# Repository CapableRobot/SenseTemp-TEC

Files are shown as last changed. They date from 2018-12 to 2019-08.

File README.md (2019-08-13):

# SenseTemp TEC

Designed by [Capable Robot Components](http://capablerobot.com).  
Follow us on [Twitter](http://twitter.com/capablerobot) for product announcements and updates.

---

**SenseTemp TEC is available for purchase at [CrowdSupply](https://www.crowdsupply.com/capable-robot-components/sensetemp) & [Mouser](https://www.mouser.com/ProductDetail/Crowd-Supply/cs-sensetemp-03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).**  

## SenseTemp TEC Features 

## Specifications

## Feather Hosts

SenseTemp TEC is designed to mate with Adafruit Feather-compatible host modules, like:

* [Adafruit Feather M4 Express](https://www.adafruit.com/product/3857)
* [Adafruit Feather M0 Express](https://www.adafruit.com/product/3403)
* [Adafruit ESP32 Feather Host](https://www.adafruit.com/product/3405)

Note that the ES8266 Feather is **NOT** supported due to the limited IO on the ESP8266.  It does not have enough pins to support the four SPI devices of the SenseTemp.

## Software

## Hardware Revisions

* [CR2ERP](revisions/CR2ERP) : Released 2018-12-18.
	* Added high-side switch for fan control
	* Removed `!EN` pin as this product will not run off of battery power and there is no need to disable RTD converter chips.
	* Added 12v to 3v regulator (and disabled 5v to 3v regulator on host board).
	* Minor footprint changes.
	* Changed `PWM` pin for TEC control.
* [CRHVEF](revisions/CRHVEF) : Initial version released 2018-12-04.

## License Information

| **Type** | **License** |
| --- | --- |
| Hardware | Copyright Capable Robot Components 2018 <br><br>This documentation describes Open Hardware and is licensed under the [CERN OHL v1.2 or later](https://www.ohwr.org/licenses/cern-ohl/license_versions/v1.2). <br/><br/> You may redistribute and modify this documentation under the terms of the CERN OHL v.1.2.  This documentation is distributed WITHOUT ANY EXPRESS OR IMPLIED WARRANTY, INCLUDING OF MERCHANTABILITY, SATISFACTORY QUALITY AND FITNESS FOR A PARTICULAR PURPOSE. Please see the CERN OHL v.1.2 for applicable conditions |
| Software | [MIT License](tree/master/LICENSE.txt) |
| Documentation | [Creative Commons Attribution-ShareAlike](https://creativecommons.org/licenses/by-sa/4.0/) License |

More detailed information about the CERN License is available in the [license](license) folder and on the [CERN website](https://www.ohwr.org/projects/cernohl/wiki).

| **OSHW Certification** |

Coming Soon

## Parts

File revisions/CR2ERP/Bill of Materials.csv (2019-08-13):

Name | Mpn | Count | Device | Value | Package | Mfg | Cost | Description
C1,C22,C23,C24,C25 | CL31X226KOHN3NE | 5 | CAP-1206 | 22u 16v | 1206 | Samsung | 0.9049
C15,C16,C19,C26 | CL21A106KPFNNNE | 4 | CAP-0805 | 10u | 0805 | Samsung | 0.19060000000000002
C21 | CKG57NX7S1C107M500JH | 1 | CAP-2220 | 100u 16v | 2220 | TDK | 3.2068
C3,C4,C6,C7,C9,C10,C12,C13,C20 | MF-CAP-0603-0.1uF | 9 | CAP-0603 | 100n | 0603 | Generic
C5,C8,C11,C14 | MF-CAP-0603-0.01uF | 4 | CAP-0603 | 10n | 0603 | Generic
D1 | MBR120VLSFT3G | 1 | DIODE-SCHOTTKY-SOD-123 | MBR120 | SOD-123 | ON Semiconductor | 0.16
D3,D4 | SMAJ12A-13-F | 2 | DIODE-DO214AA | SMAJ12A | DO214AA | Diodes Inc. | 0.236
FB1,FB2,FB3,FB4 | BK1608HW601-T | 4 | FER-0603 | 600R | 0603 | Taiyo Yuden | 0.11350000000000002
L3,L4 | HCF1007-100-R | 2 | IND-HCF1007 | 10uH | IND-HCF1007 | Eaton | 4.3222
PWR | 43045-0200 | 1 | CONN-2-MFJR-RA |  | CONN-MFJR-RA-2X1 | Molex | 0.7328
Q3 | FDS6630A | 1 | MOSFET-NCH-SOIC8 | 6.5A/30V/38mΩ | SOIC127P600X175-8 | ON Semiconductor | 0.316
R2,R3,R18 | MF-RES-0603-1K | 3 | RES-0603 | 1k | 0603 | Generic
R20,R21 | MF-RES-0603-4.7K | 2 | RES-0603 | 4K7 | 0603 | Generic
R4,R6,R8,R10,R16,R17,R19,R23 | MF-RES-0603-10K | 8 | RES-0603 | 10k | 0603 | Generic
R5,R7,R9,R11 | ERA3ARW432V | 4 | RES-0603 | 4k3 0.05% | 0603 | Panasonic | 1.7916
RTD1 | 3221-16-0300-00 | 1 | CONN-16-ZT |  | CONN-2X8-050-SMT-ZT | CNC Tech | 0.946
TEC/FAN | 43045-0400 | 1 | CONN-4-MFJR-RA |  | CONN-MFJR-RA-2X2 | Molex | 1.1052
U1 | NCP1117ST50T3G | 1 | VREG-LDO | NCP1117 3v3 | SOT230P700X180-4 | ON Semiconductor | 0.238
U10 | NCV8461DR2G | 1 | NCV8461 |  | SOIC127P600X175-8 | ON Semiconductor | 0.753
U2 | AT21CS01-STUM10-T | 1 | AT21CS01 |  | SOT23 | Microchip | 0.1836
U3,U4,U5,U6 | MAX31865ATP+ | 4 | MAX31865 |  | QFN65P500X500X100-21T325 | Maxim Integrated | 12.336
U7 | AP2112K-3.3TRG1 | 1 | MIC5225 | 3v3 | SOT25 | Diodes Inc. | 0.15
U8 | VNH5019ATR-E | 1 | VNH5019 |  | SOP100P1900X235-30-EP | STMicroelectronics | 5.75

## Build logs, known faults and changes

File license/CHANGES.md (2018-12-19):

Here we are compiling a community changelog.

If you come up with a modification of our designs, please share it
with the community, log your changes below, and upload the files to
our GitHub repository.

# Change Format

**NAME** on DATE by *Your name*.
Description of modification

# Change Log

* **[CR2ERP](https://github.com/CapableRobot/SenseTemp/tree/master/revisions/CR2ERP)** on 2018-12-18 by *Chris Osterwood*
	* Added high-side switch for fan control
	* Removed `!EN` pin as this product will not run off of battery power and there is no need to disable RTD converter chips.
	* Added 12v to 3v regulator (and disable 5v to 3v regulator on host board).
	* Minor footprint changes.
	* Changed `PWM` pin for TEC control.
	* Add user LED near RTD connector.
* **[CRHVEF](https://github.com/CapableRobot/SenseTemp/tree/master/revisions/CRHVEF)** 2018-12-04 by *Chris Osterwood*

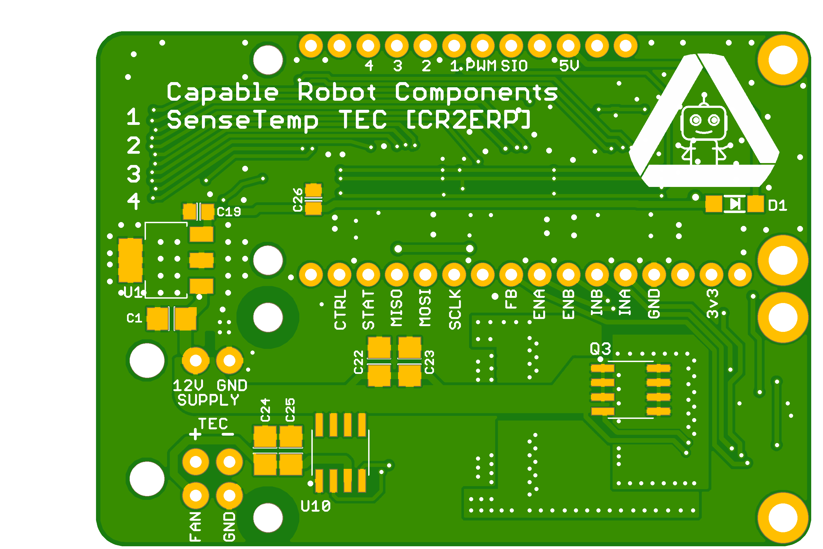
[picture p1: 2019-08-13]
revisions/CR2ERP/SenseThermo TEC - CR2ERP - Bottom.png

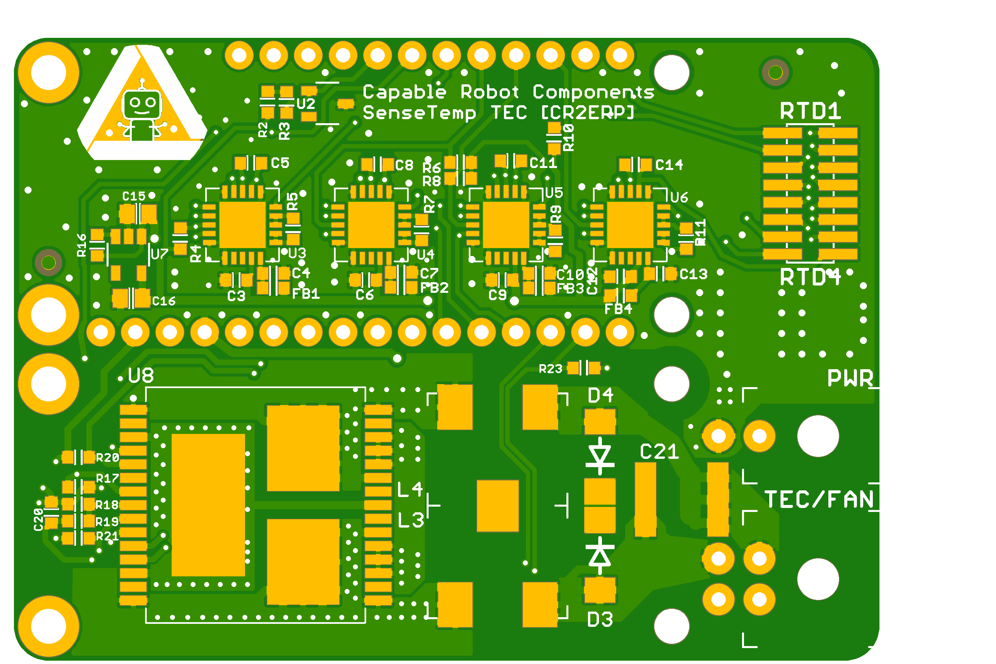
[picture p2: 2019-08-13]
revisions/CR2ERP/SenseThermo TEC - CR2ERP - Top.png

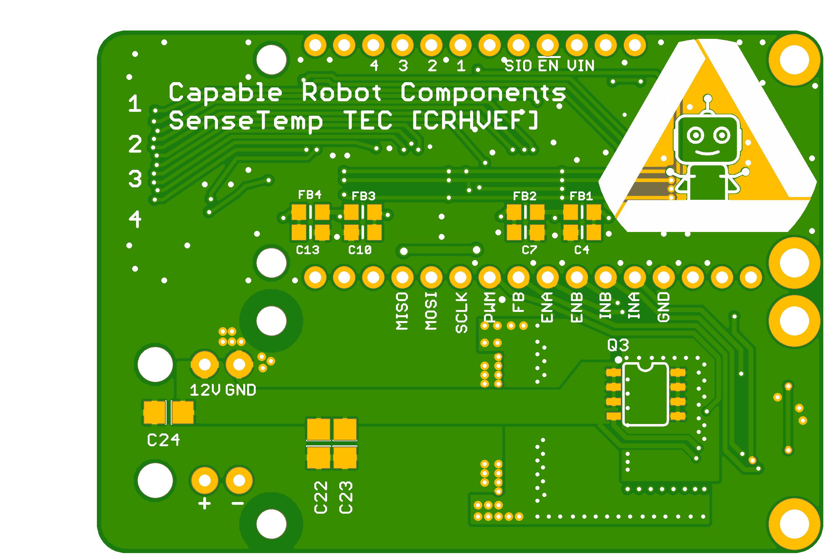
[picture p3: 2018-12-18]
revisions/CRHVEF/SenseThermo TEC - CRHVEF - bottom.png

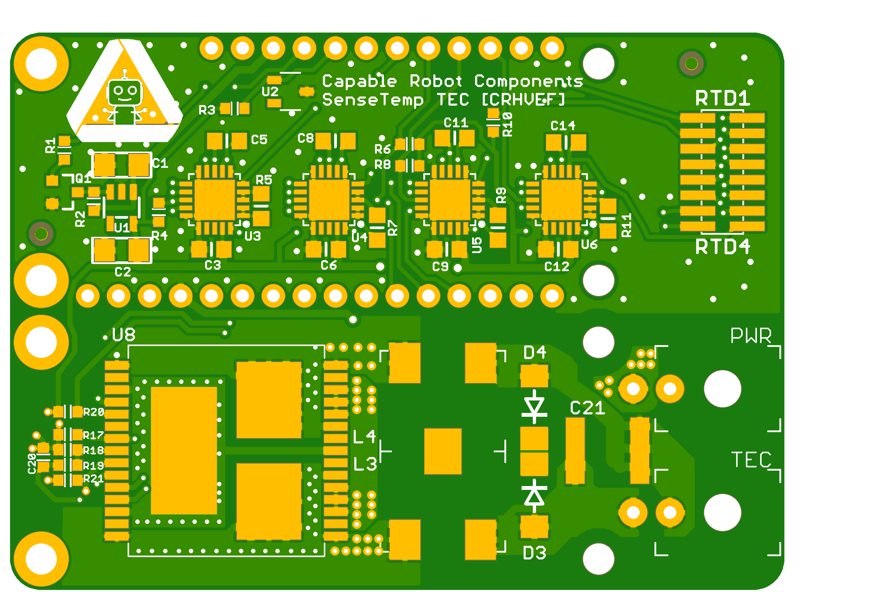
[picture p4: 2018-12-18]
revisions/CRHVEF/SenseThermo TEC - CRHVEF - top.png

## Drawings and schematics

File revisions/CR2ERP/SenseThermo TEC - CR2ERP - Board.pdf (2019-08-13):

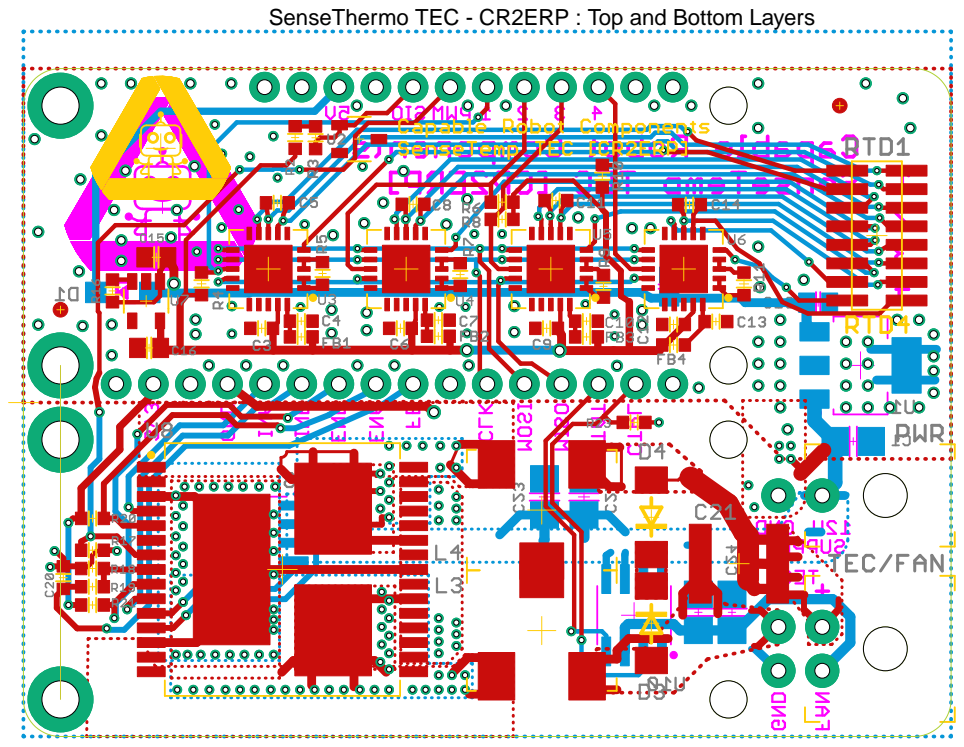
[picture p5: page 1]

SenseThermo TEC - CR2ERP : Top and Bottom Layers

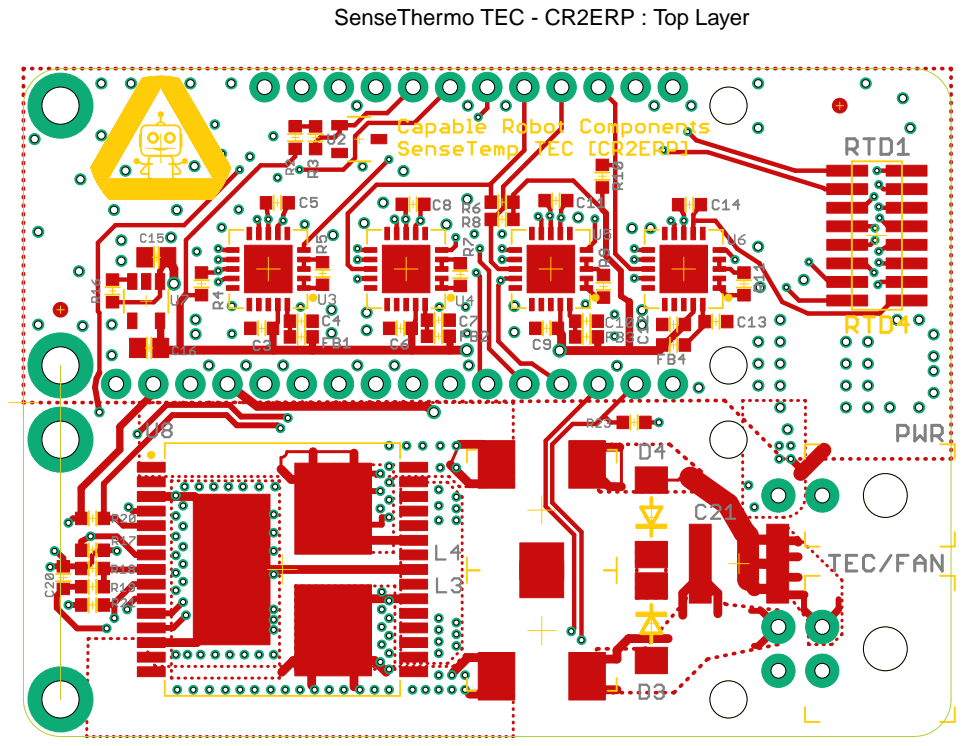
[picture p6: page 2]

SenseThermo TEC - CR2ERP : Top Layer

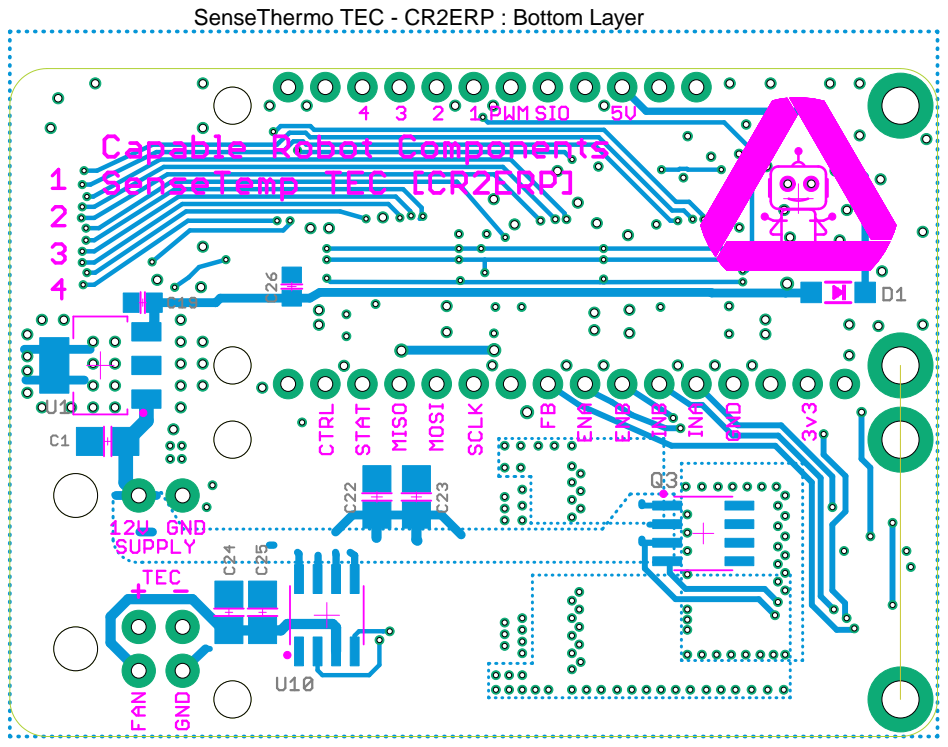
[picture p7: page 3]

SenseThermo TEC - CR2ERP : Bottom Layer

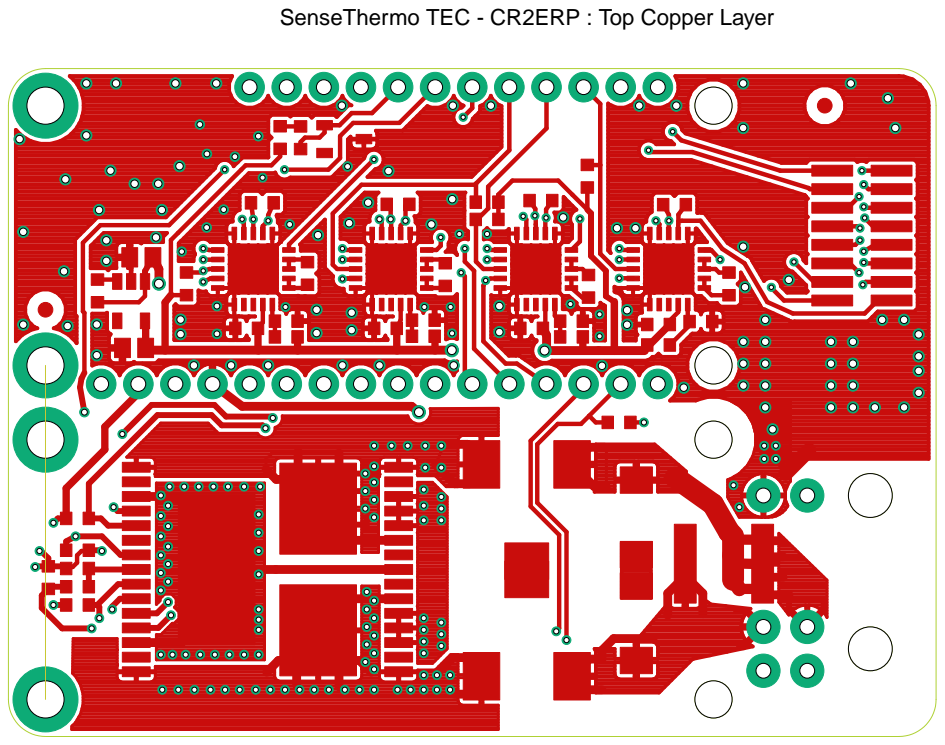
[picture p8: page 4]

SenseThermo TEC - CR2ERP : Top Copper Layer

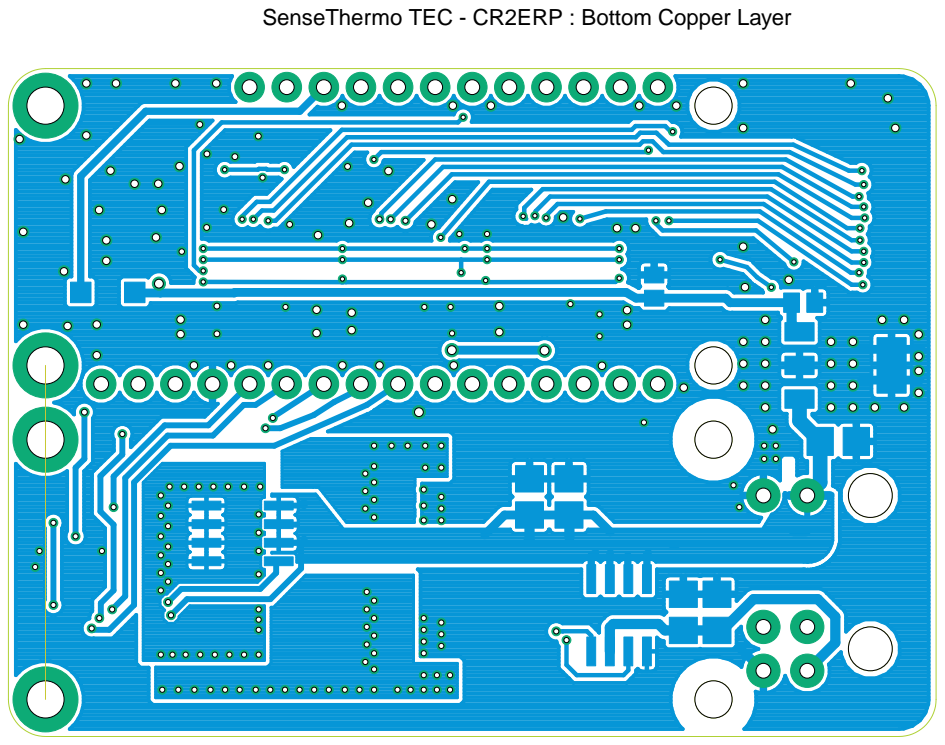
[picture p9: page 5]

SenseThermo TEC - CR2ERP : Bottom Copper Layer

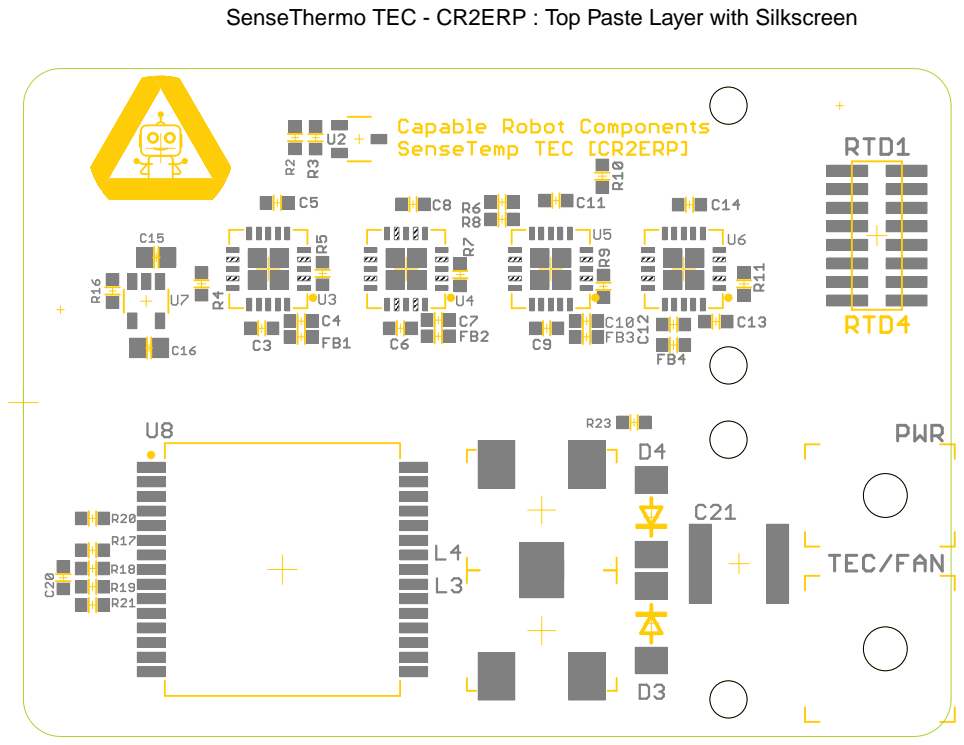
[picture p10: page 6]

SenseThermo TEC - CR2ERP : Top Paste Layer with Silkscreen

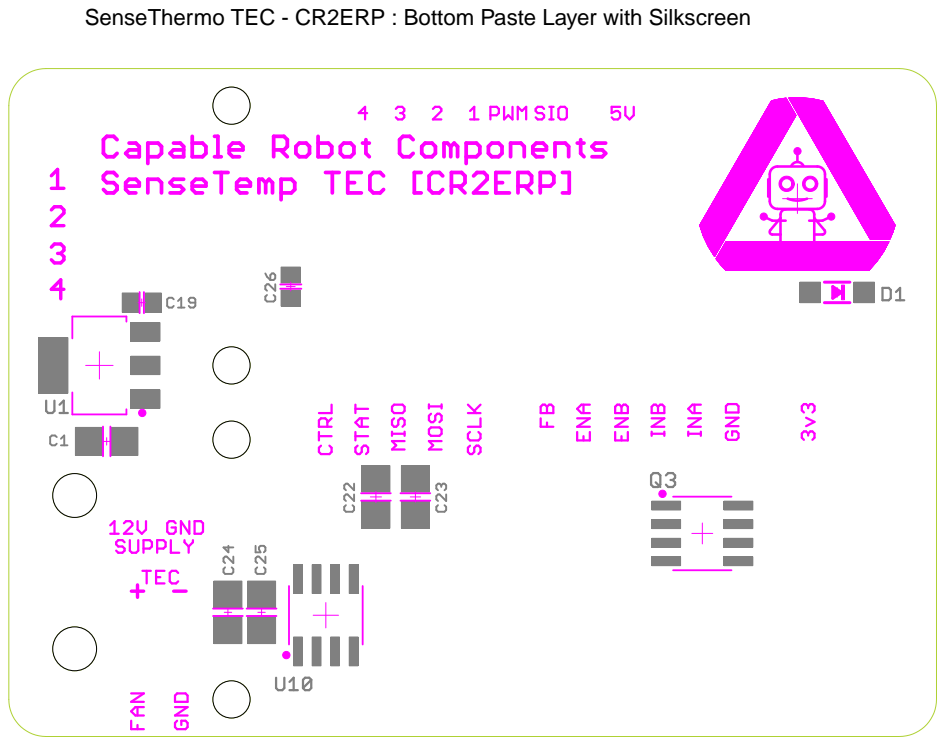
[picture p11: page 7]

SenseThermo TEC - CR2ERP : Bottom Paste Layer with Silkscreen

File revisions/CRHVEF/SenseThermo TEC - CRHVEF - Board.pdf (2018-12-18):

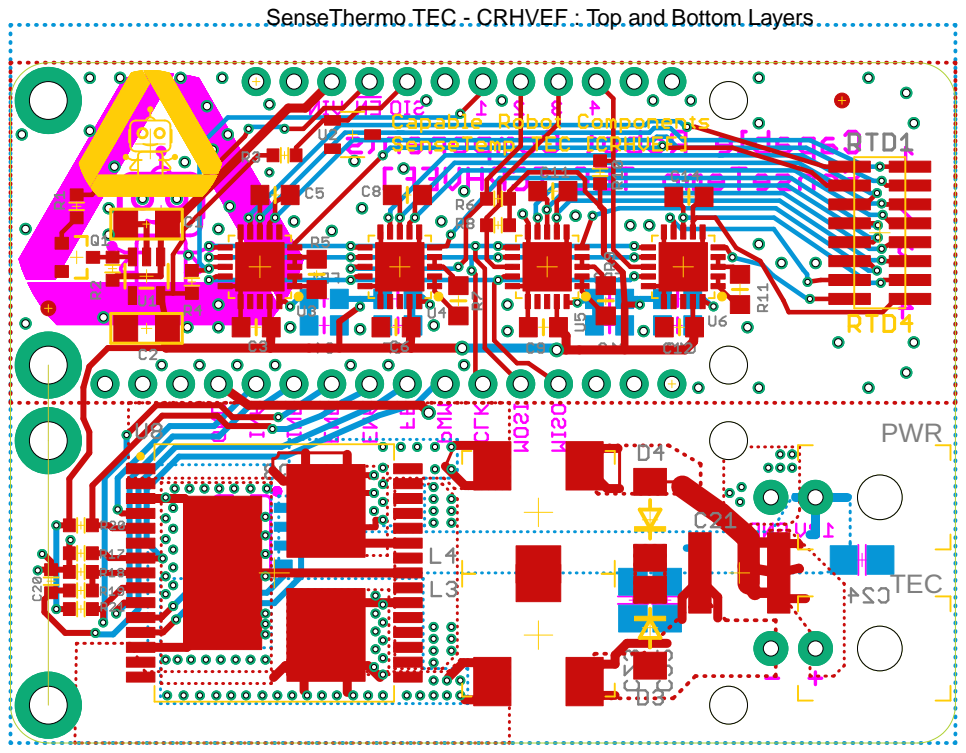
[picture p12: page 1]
TEC; PWR

SenseThermo TEC - CRHVEF : Top and Bottom Layers

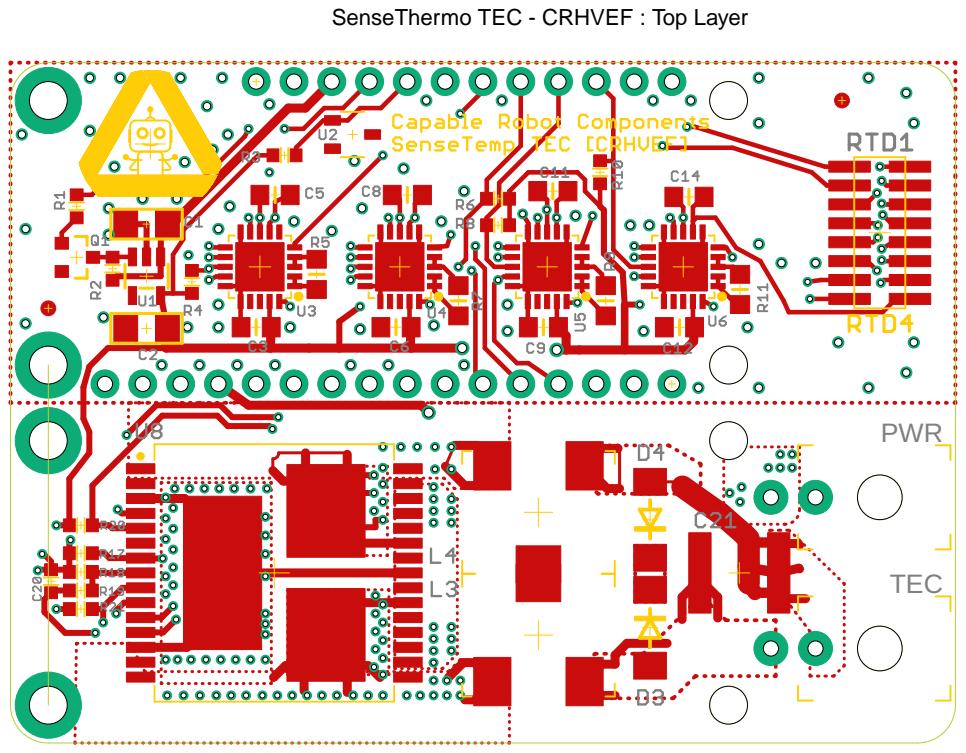
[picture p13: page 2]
TEC; PWR

SenseThermo TEC - CRHVEF : Top Layer

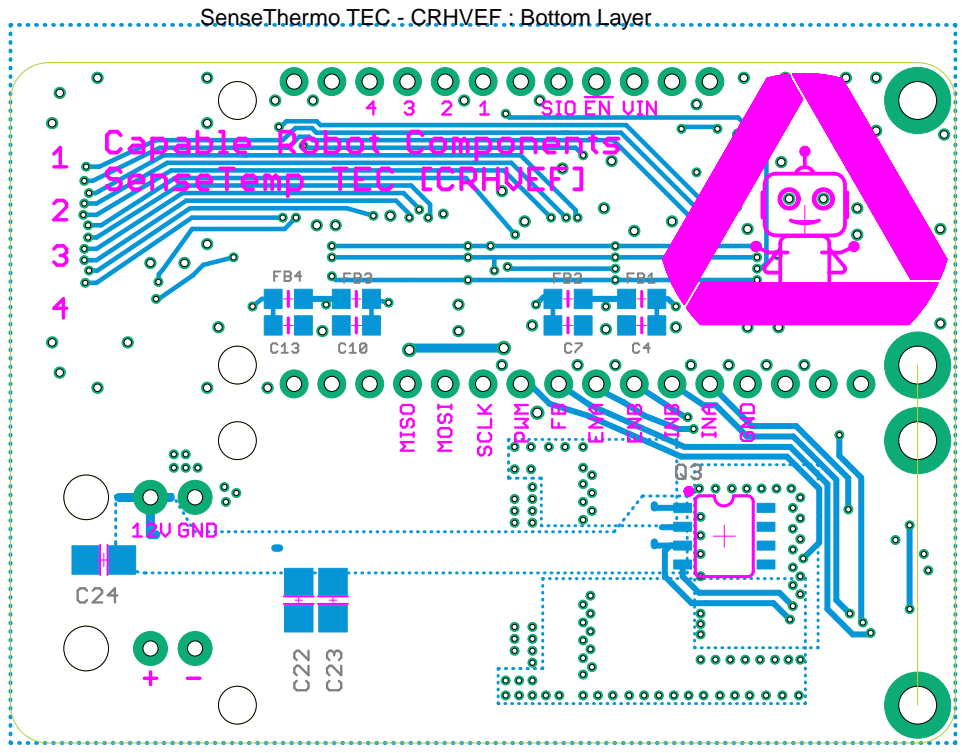
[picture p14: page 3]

SenseThermo TEC - CRHVEF : Bottom Layer

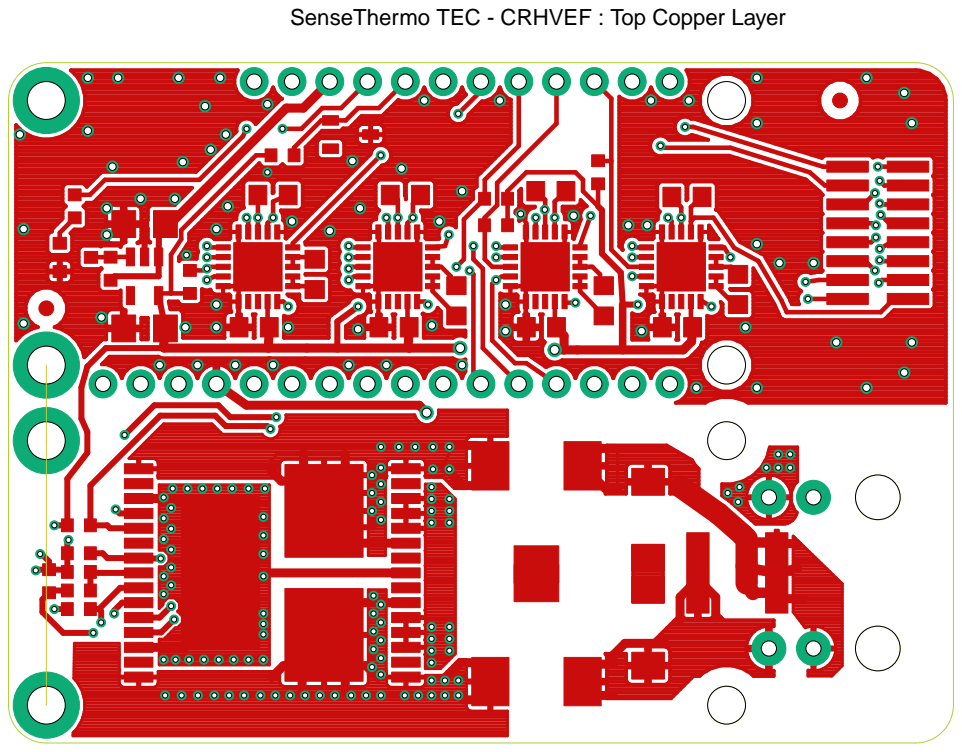
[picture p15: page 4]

SenseThermo TEC - CRHVEF : Top Copper Layer

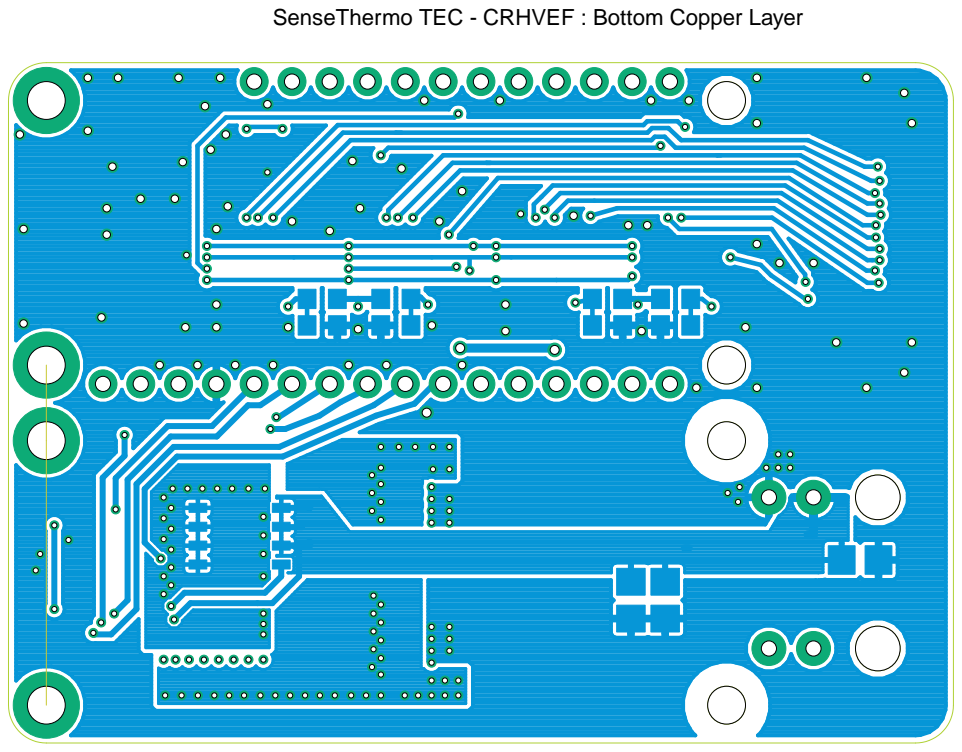
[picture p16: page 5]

SenseThermo TEC - CRHVEF : Bottom Copper Layer

TEC; PWR

SenseThermo TEC - CRHVEF : Top Paste Layer with Silkscreen


SenseThermo TEC - CRHVEF : Bottom Paste Layer with Silkscreen

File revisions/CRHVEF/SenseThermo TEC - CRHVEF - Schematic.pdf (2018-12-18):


Name | Revision Capable Robot Components
SenseTemp TEC | CRHVEF | License 12/18/18 4:24 PM 1/4 CERN OHL v1.2

URL
https://github.com/CapableRobot/SenseTemp-TEC


4x RTD resistance at 0°C
Use high quality 1% or better resistors

Name | Revision Capable Robot Components
SenseTemp TEC | CRHVEF | License 12/18/18 4:24 PM 2/4 CERN OHL v1.2

URL
https://github.com/CapableRobot/SenseTemp-TEC


Name | Revision Capable Robot Components
SenseTemp TEC | CRHVEF | License 12/18/18 4:24 PM 3/4 CERN OHL v1.2

URL
https://github.com/CapableRobot/SenseTemp-TEC


Name | Revision Capable Robot Components
SenseTemp TEC | CRHVEF | License 12/18/18 4:24 PM 4/4 CERN OHL v1.2

URL
https://github.com/CapableRobot/SenseTemp-TEC





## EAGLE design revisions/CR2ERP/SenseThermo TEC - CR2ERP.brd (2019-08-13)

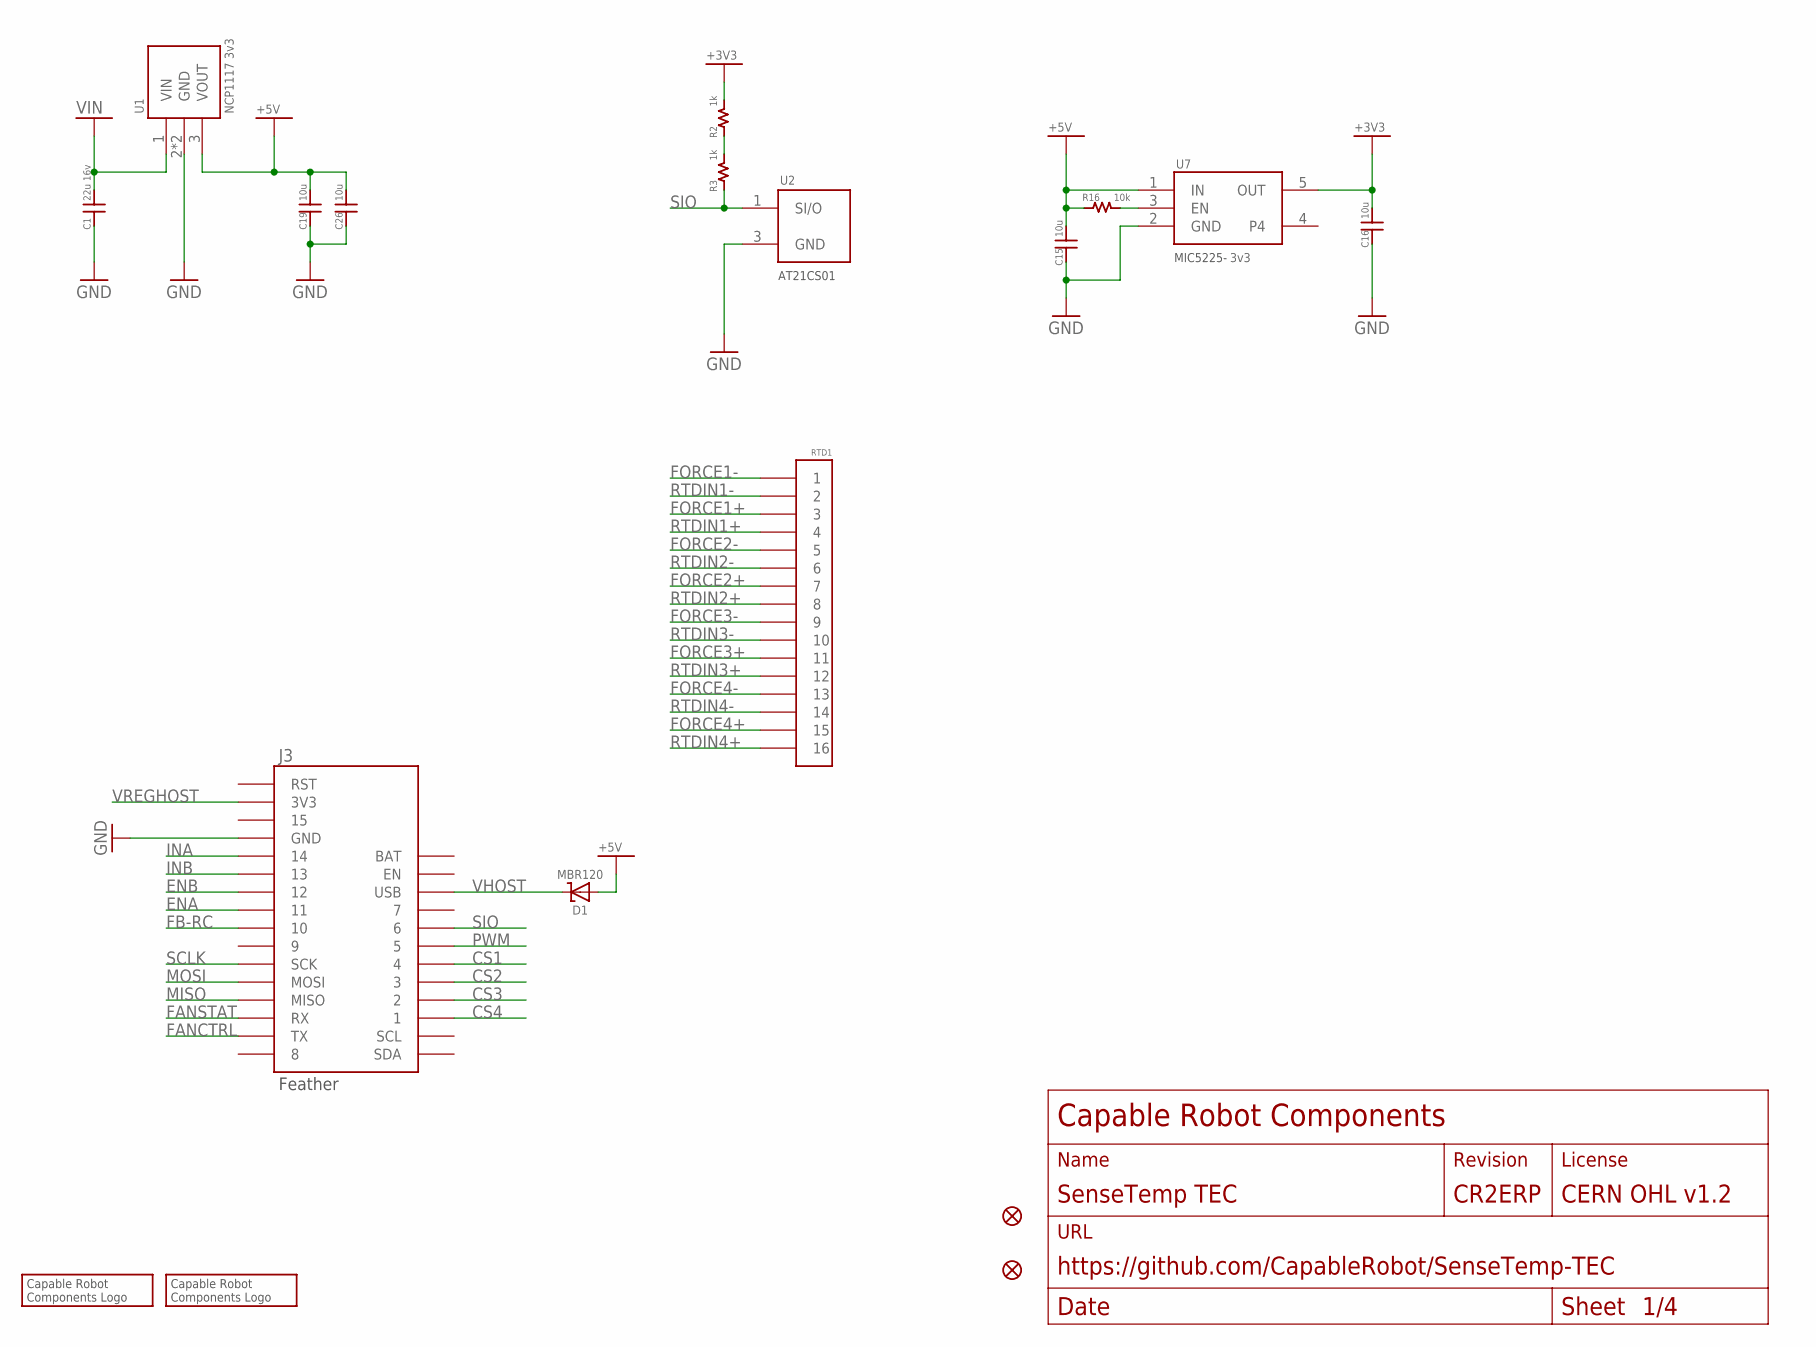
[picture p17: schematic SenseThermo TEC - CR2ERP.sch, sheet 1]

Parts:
C1: 22u 16v; 1206
C15, C16, C19, C26: 10u; 0805
D1: MBR120; SOD-123; MPN MBR120VLSFT3G
FID1, FID2: FIDUCIAL""; FIDUCIAL_1MM
J3: FEATHERPTH; FEATHER-PTH
LOGO1: CRC-LOGO7SILK; CRC-LOGO-7-SILK
LOGO2: CRC-LOGO5; CRC-LOGO-5
R2, R3: 1k; 0603
R16: 10k; 0603
RTD1: CONN-16ZT; CONN-2X8-050-SMT-ZT; MPN 3221-16-0300-00
U1: NCP1117 3v3; SOT230P700X180-4; MPN NCP1117ST50T3G
U2: AT21CS01; SOT23
U7: 3v3; SOT25

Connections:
+3V3: C16.P$2, R2.2, U7.5 (OUT); also elsewhere on the board
+5V: C15.P$2, C19.P$2, C26.P$2, D1.A, R16.1, U1.3 (VOUT), U7.1 (IN)
CS1: J3.4; also elsewhere on the board
CS2: J3.3; also elsewhere on the board
CS3: J3.2; also elsewhere on the board
CS4: J3.1; also elsewhere on the board
ENA: J3.11; also elsewhere on the board
ENB: J3.12; also elsewhere on the board
FANCTRL: J3.TX; also elsewhere on the board
FANSTAT: J3.RX; also elsewhere on the board
FB-RC: J3.10; also elsewhere on the board
FORCE1+: RTD1.3; also elsewhere on the board
FORCE1-: RTD1.1; also elsewhere on the board
FORCE2+: RTD1.7; also elsewhere on the board
FORCE2-: RTD1.5; also elsewhere on the board
FORCE3+: RTD1.11; also elsewhere on the board
FORCE3-: RTD1.9; also elsewhere on the board
FORCE4+: RTD1.15; also elsewhere on the board
FORCE4-: RTD1.13; also elsewhere on the board
GND: C1.P$1, C15.P$1, C16.P$1, C19.P$1, C26.P$1, J3.GND, U1.2 (GND), U1.4 (GND), U2.3 (GND), U7.2 (GND); also elsewhere on the board
INA: J3.14; also elsewhere on the board
INB: J3.13; also elsewhere on the board
MISO: J3.MISO; also elsewhere on the board
MOSI: J3.MOSI; also elsewhere on the board
unnamed: R2.1, R3.2
unnamed: R16.2, U7.3 (EN)
PWM: J3.5; also elsewhere on the board
RTDIN1+: RTD1.4; also elsewhere on the board
RTDIN1-: RTD1.2; also elsewhere on the board
RTDIN2+: RTD1.8; also elsewhere on the board
RTDIN2-: RTD1.6; also elsewhere on the board
RTDIN3+: RTD1.12; also elsewhere on the board
RTDIN3-: RTD1.10; also elsewhere on the board
RTDIN4+: RTD1.16; also elsewhere on the board
RTDIN4-: RTD1.14; also elsewhere on the board
SCLK: J3.SCK; also elsewhere on the board
SIO: J3.6, R3.1, U2.1 (SI/O)
VHOST: D1.C, J3.USB
VIN: C1.P$2, U1.1 (VIN); also elsewhere on the board
VREGHOST: J3.3V3; also elsewhere on the board

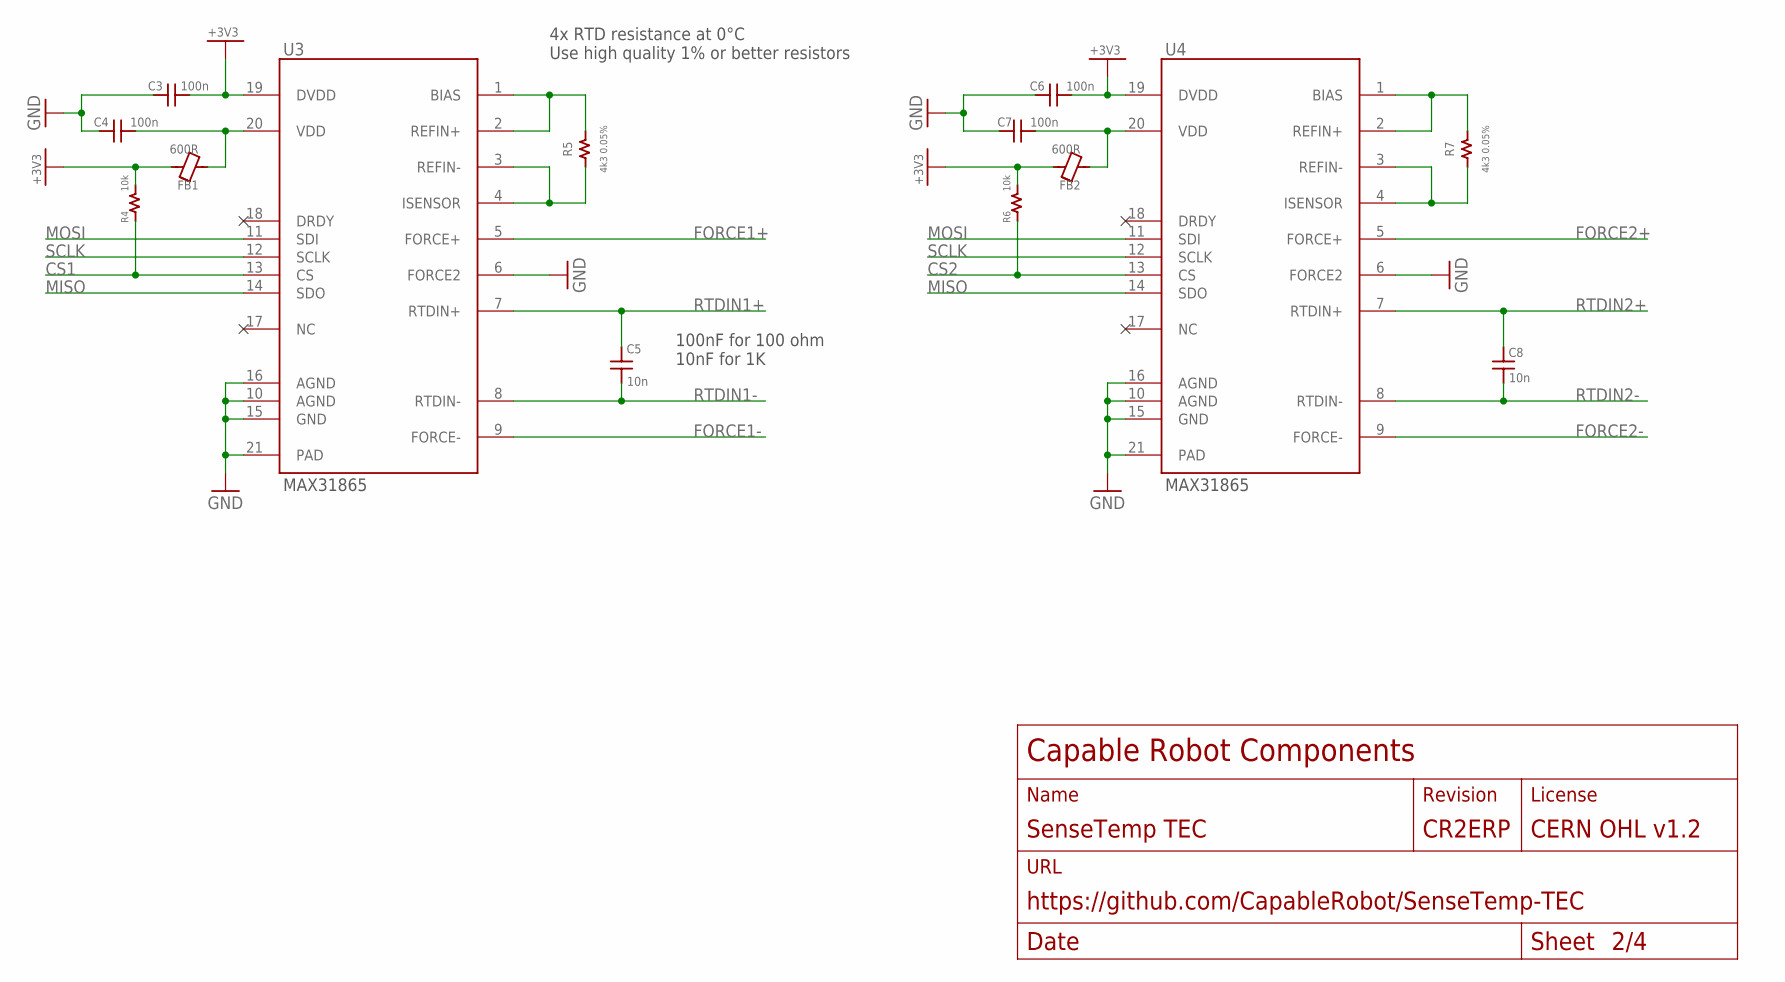
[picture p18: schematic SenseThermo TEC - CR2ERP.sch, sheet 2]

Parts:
C3, C4, C6, C7: 100n; 0603
C5, C8: 10n; 0603
FB1, FB2: 600R; 0603
R4, R6: 10k; 0603
R5, R7: 4k3 0.05%; 0603
U3, U4: MAX31865; QFN65P500X500X100-21T325

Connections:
+3V3: C3.1, C6.1, FB1.2, FB2.2, R4.2, R6.2, U3.19 (DVDD), U4.19 (DVDD); also elsewhere on the board
CS1: R4.1, U3.13 (CS); also elsewhere on the board
CS2: R6.1, U4.13 (CS); also elsewhere on the board
FORCE1+: U3.5 (FORCE+); also elsewhere on the board
FORCE1-: U3.9 (FORCE-); also elsewhere on the board
FORCE2+: U4.5 (FORCE+); also elsewhere on the board
FORCE2-: U4.9 (FORCE-); also elsewhere on the board
GND: C3.2, C4.2, C6.2, C7.2, U3.6 (FORCE2), U3.10 (AGND), U3.15 (GND), U3.16 (AGND), U3.21 (PAD), U4.6 (FORCE2), U4.10 (AGND), U4.15 (GND), U4.16 (AGND), U4.21 (PAD); also elsewhere on the board
MISO: U3.14 (SDO), U4.14 (SDO); also elsewhere on the board
MOSI: U3.11 (SDI), U4.11 (SDI); also elsewhere on the board
unnamed: R5.2, U3.1 (BIAS), U3.2 (REFIN+)
unnamed: R5.1, U3.3 (REFIN-), U3.4 (ISENSOR)
unnamed: C4.1, FB1.1, U3.20 (VDD)
unnamed: R7.2, U4.1 (BIAS), U4.2 (REFIN+)
unnamed: R7.1, U4.3 (REFIN-), U4.4 (ISENSOR)
unnamed: C7.1, FB2.1, U4.20 (VDD)
RTDIN1+: C5.1, U3.7 (RTDIN+); also elsewhere on the board
RTDIN1-: C5.2, U3.8 (RTDIN-); also elsewhere on the board
RTDIN2+: C8.1, U4.7 (RTDIN+); also elsewhere on the board
RTDIN2-: C8.2, U4.8 (RTDIN-); also elsewhere on the board
SCLK: U3.12 (SCLK), U4.12 (SCLK); also elsewhere on the board

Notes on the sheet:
4x RTD resistance at 0°C Use high quality 1% or better resistors
100nF for 100 ohm 10nF for 1K

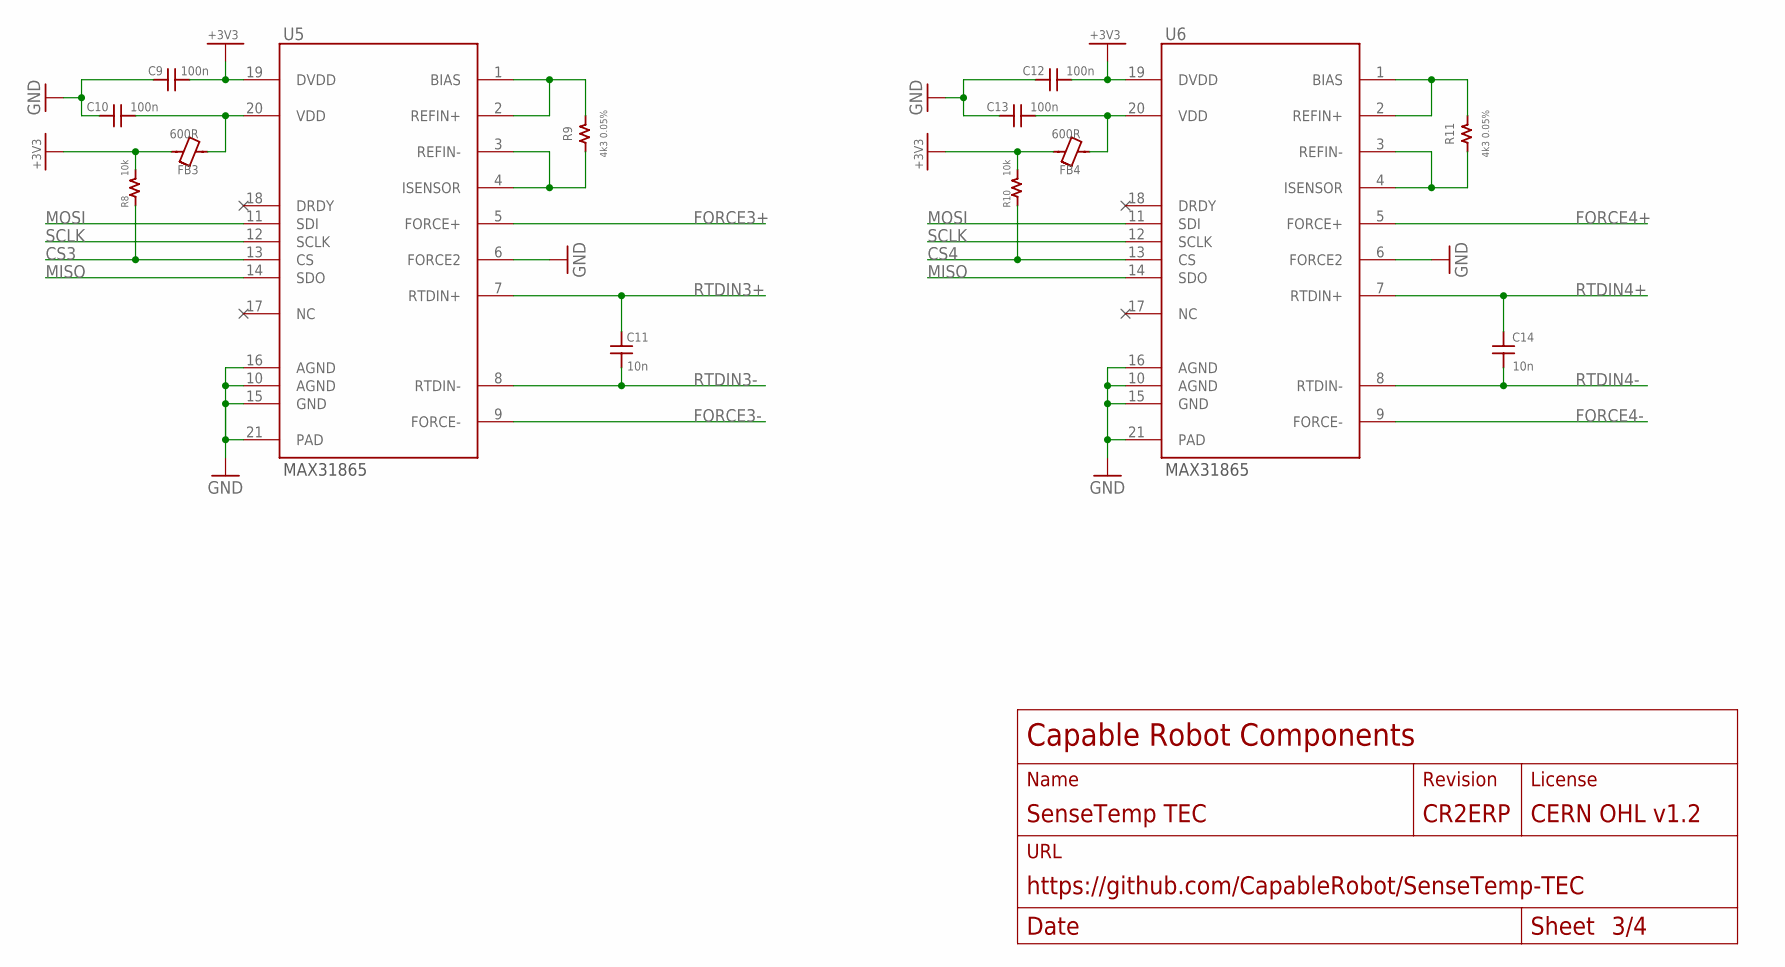
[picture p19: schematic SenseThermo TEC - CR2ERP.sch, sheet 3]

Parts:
C9, C10, C12, C13: 100n; 0603
C11, C14: 10n; 0603
FB3, FB4: 600R; 0603
R8, R10: 10k; 0603
R9, R11: 4k3 0.05%; 0603
U5, U6: MAX31865; QFN65P500X500X100-21T325

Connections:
+3V3: C9.1, C12.1, FB3.2, FB4.2, R8.2, R10.2, U5.19 (DVDD), U6.19 (DVDD); also elsewhere on the board
CS3: R8.1, U5.13 (CS); also elsewhere on the board
CS4: R10.1, U6.13 (CS); also elsewhere on the board
FORCE3+: U5.5 (FORCE+); also elsewhere on the board
FORCE3-: U5.9 (FORCE-); also elsewhere on the board
FORCE4+: U6.5 (FORCE+); also elsewhere on the board
FORCE4-: U6.9 (FORCE-); also elsewhere on the board
GND: C9.2, C10.2, C12.2, C13.2, U5.6 (FORCE2), U5.10 (AGND), U5.15 (GND), U5.16 (AGND), U5.21 (PAD), U6.6 (FORCE2), U6.10 (AGND), U6.15 (GND), U6.16 (AGND), U6.21 (PAD); also elsewhere on the board
MISO: U5.14 (SDO), U6.14 (SDO); also elsewhere on the board
MOSI: U5.11 (SDI), U6.11 (SDI); also elsewhere on the board
unnamed: R9.2, U5.1 (BIAS), U5.2 (REFIN+)
unnamed: R9.1, U5.3 (REFIN-), U5.4 (ISENSOR)
unnamed: C10.1, FB3.1, U5.20 (VDD)
unnamed: R11.2, U6.1 (BIAS), U6.2 (REFIN+)
unnamed: R11.1, U6.3 (REFIN-), U6.4 (ISENSOR)
unnamed: C13.1, FB4.1, U6.20 (VDD)
RTDIN3+: C11.1, U5.7 (RTDIN+); also elsewhere on the board
RTDIN3-: C11.2, U5.8 (RTDIN-); also elsewhere on the board
RTDIN4+: C14.1, U6.7 (RTDIN+); also elsewhere on the board
RTDIN4-: C14.2, U6.8 (RTDIN-); also elsewhere on the board
SCLK: U5.12 (SCLK), U6.12 (SCLK); also elsewhere on the board

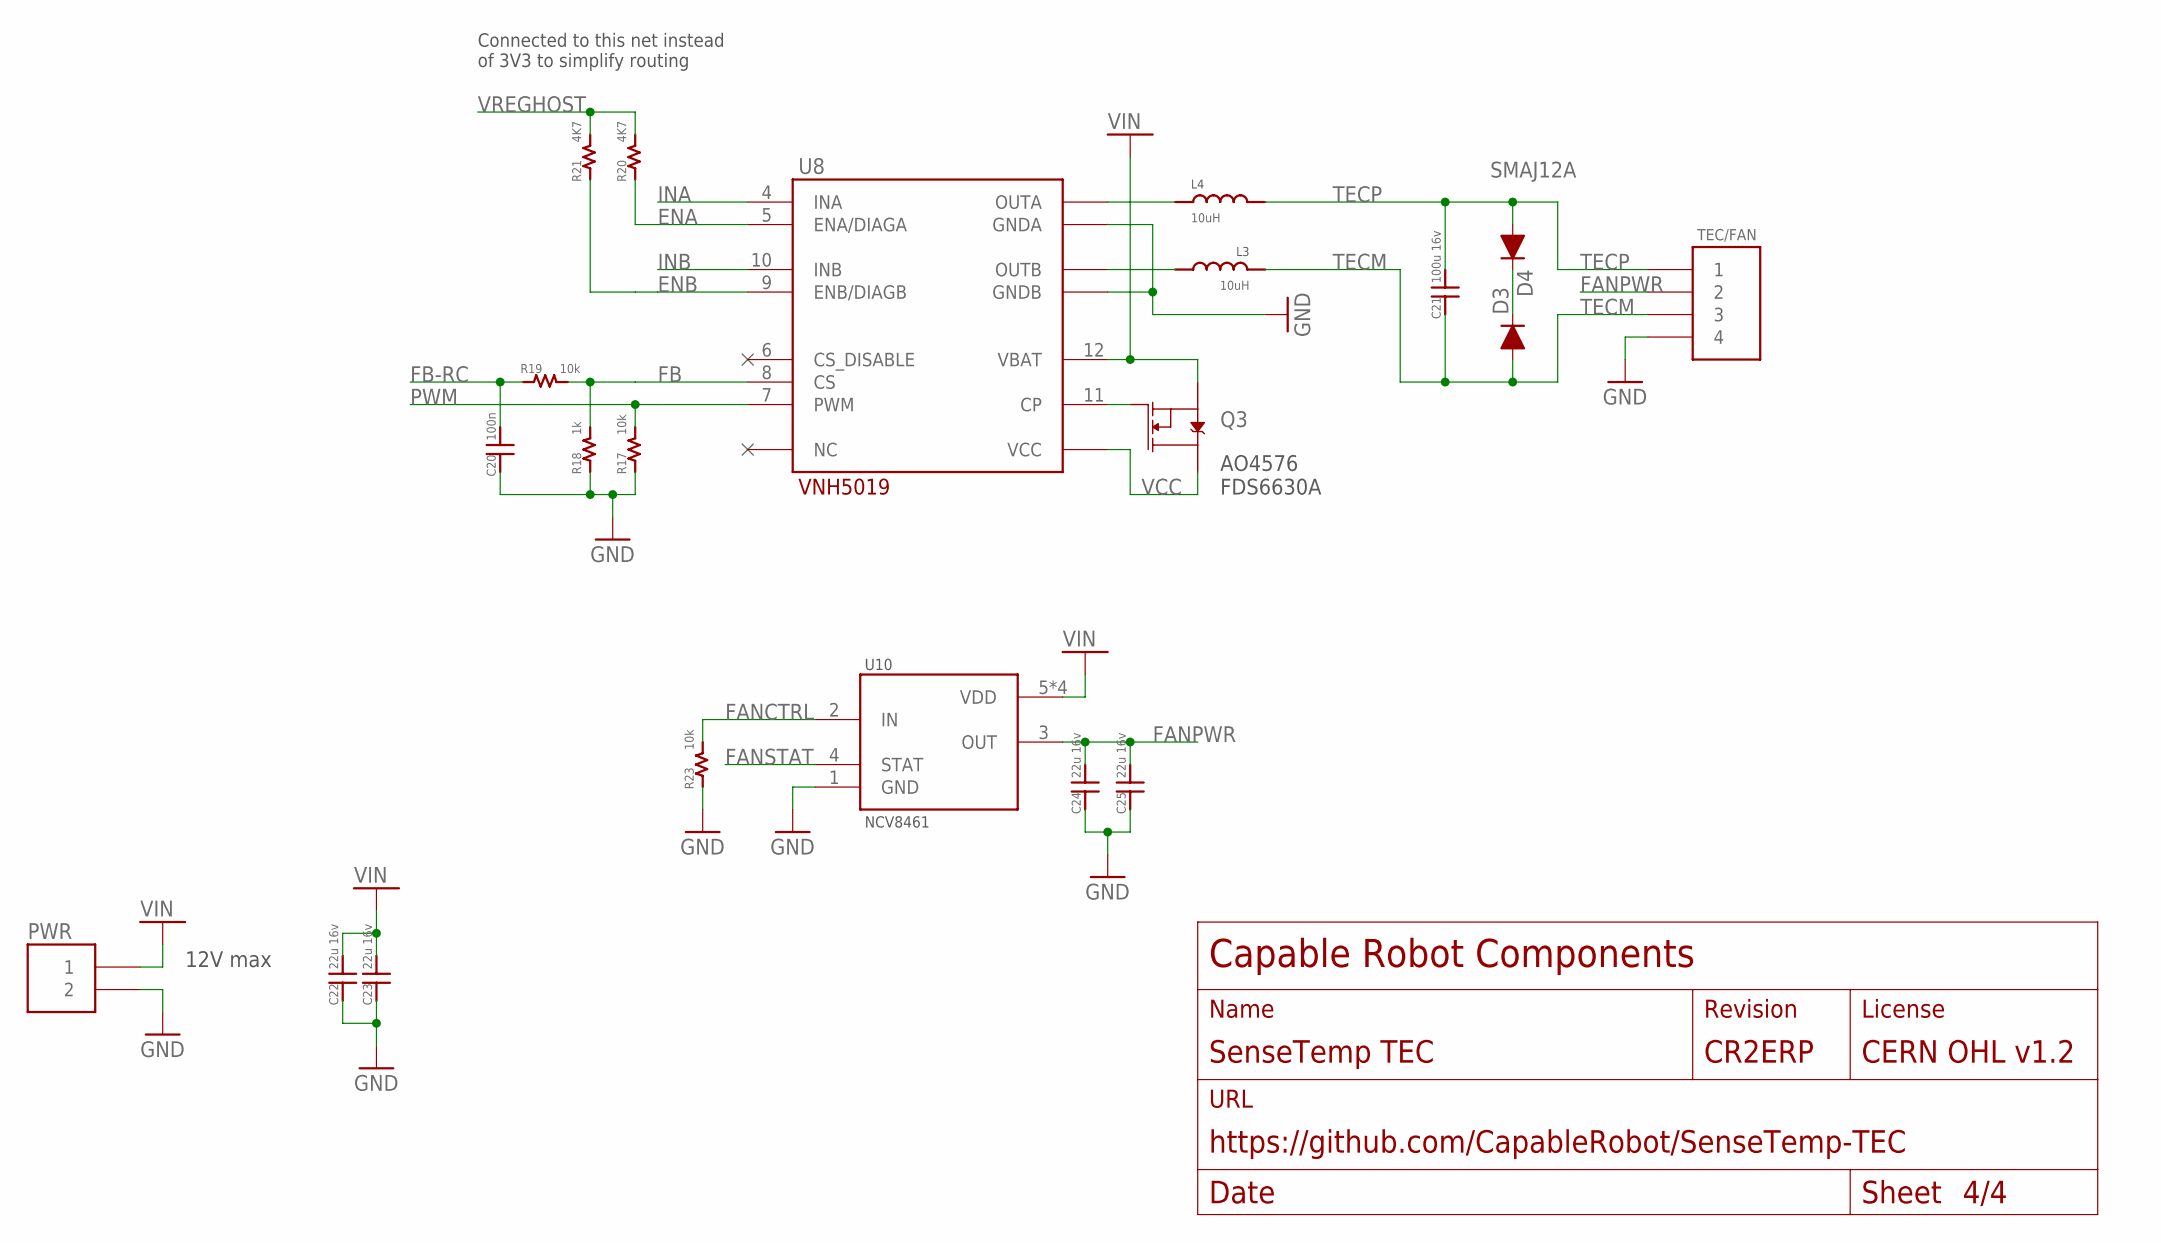
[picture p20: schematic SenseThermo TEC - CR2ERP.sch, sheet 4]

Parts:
C20: 100n; 0603
C21: 100u 16v; 2220
C22, C23, C24, C25: 22u 16v; 1206
D3, D4: SMAJ12A; DO214AA; MPN SMAJ12A-13-F
L3, L4: 10uH; IND-HCF1007
PWR: CONN-2-MFJR-RA; CONN-MFJR-RA-2X1
Q3: 6.5A/30V/38mΩ; SOIC127P600X175-8; MPN FDS6630A
R17, R19, R23: 10k; 0603
R18: 1k; 0603
R20, R21: 4K7; 0603
TEC/FAN: CONN-4-MFJR-RA; CONN-MFJR-RA-2X2
U8: VNH5019; SOP100P1900X235-30-EP
U10: NCV8461; SOIC127P600X175-8; MPN NCV8461DR2G

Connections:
CP1: Q3.4 (G), U8.11 (CP)
ENA: R20.1, U8.5 (ENA/DIAGA); also elsewhere on the board
ENB: R21.1, U8.9 (ENB/DIAGB); also elsewhere on the board
FANCTRL: R23.2, U10.2 (IN); also elsewhere on the board
FANPWR: C24.P$2, C25.P$2, TEC/FAN.2, U10.3 (OUT)
FANSTAT: U10.4 (STAT); also elsewhere on the board
FB: R18.2, R19.2, U8.8 (CS)
FB-RC: C20.2, R19.1; also elsewhere on the board
GND: C20.1, C22.P$1, C23.P$1, C24.P$1, C25.P$1, PWR.2, R17.1, R18.1, R23.1, TEC/FAN.4, U8.18 (GNDB), U8.19 (GNDB), U8.20 (GNDB), U8.26 (GNDA), U8.27 (GNDA), U8.28 (GNDA), U10.1 (GND); also elsewhere on the board
INA: U8.4 (INA); also elsewhere on the board
INB: U8.10 (INB); also elsewhere on the board
OUTA1: L4.1, U8.1 (OUTA), U8.25 (OUTA), U8.30 (OUTA), U8.OUTA
OUTB1: L3.2, U8.15 (OUTB), U8.16 (OUTB), U8.21 (OUTB), U8.OUTB
PWM: R17.2, U8.7 (PWM); also elsewhere on the board
SNUB1: D3.C, D4.C
TECM: C21.1, D3.A, L3.1, TEC/FAN.3
TECP: C21.2, D4.A, L4.2, TEC/FAN.1
VCC: Q3.5 (D), Q3.6 (D), Q3.7 (D), Q3.8 (D), U8.3 (VCC), U8.13 (VCC), U8.23 (VCC), U8.VCC
VIN: C22.P$2, C23.P$2, PWR.1, Q3.1 (S), Q3.2 (S), Q3.3 (S), U8.12 (VBAT), U10.5 (VDD), U10.6 (VDD), U10.7 (VDD), U10.8 (VDD); also elsewhere on the board
VREGHOST: R20.2, R21.2; also elsewhere on the board

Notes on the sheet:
12V max
AO4576 FDS6630A
Connected to this net instead of 3V3 to simplify routing

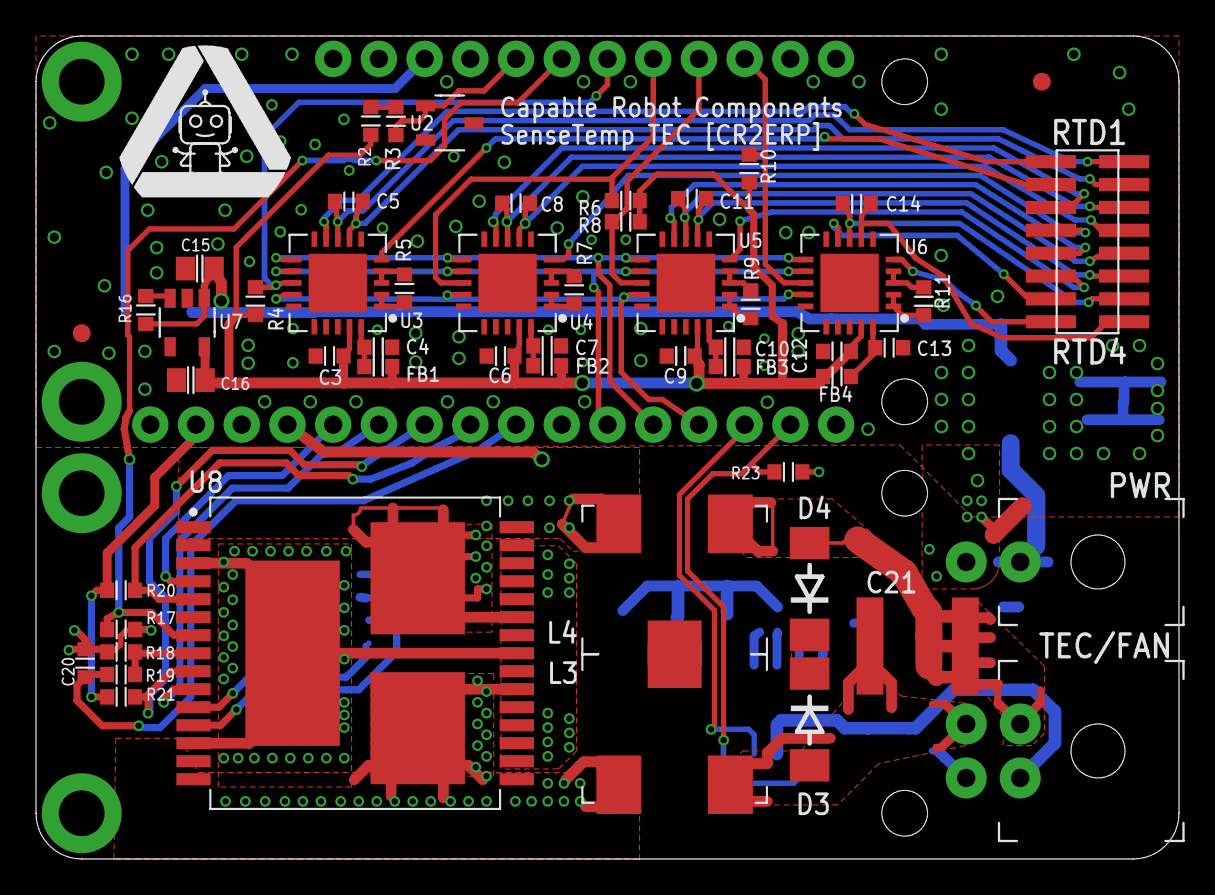
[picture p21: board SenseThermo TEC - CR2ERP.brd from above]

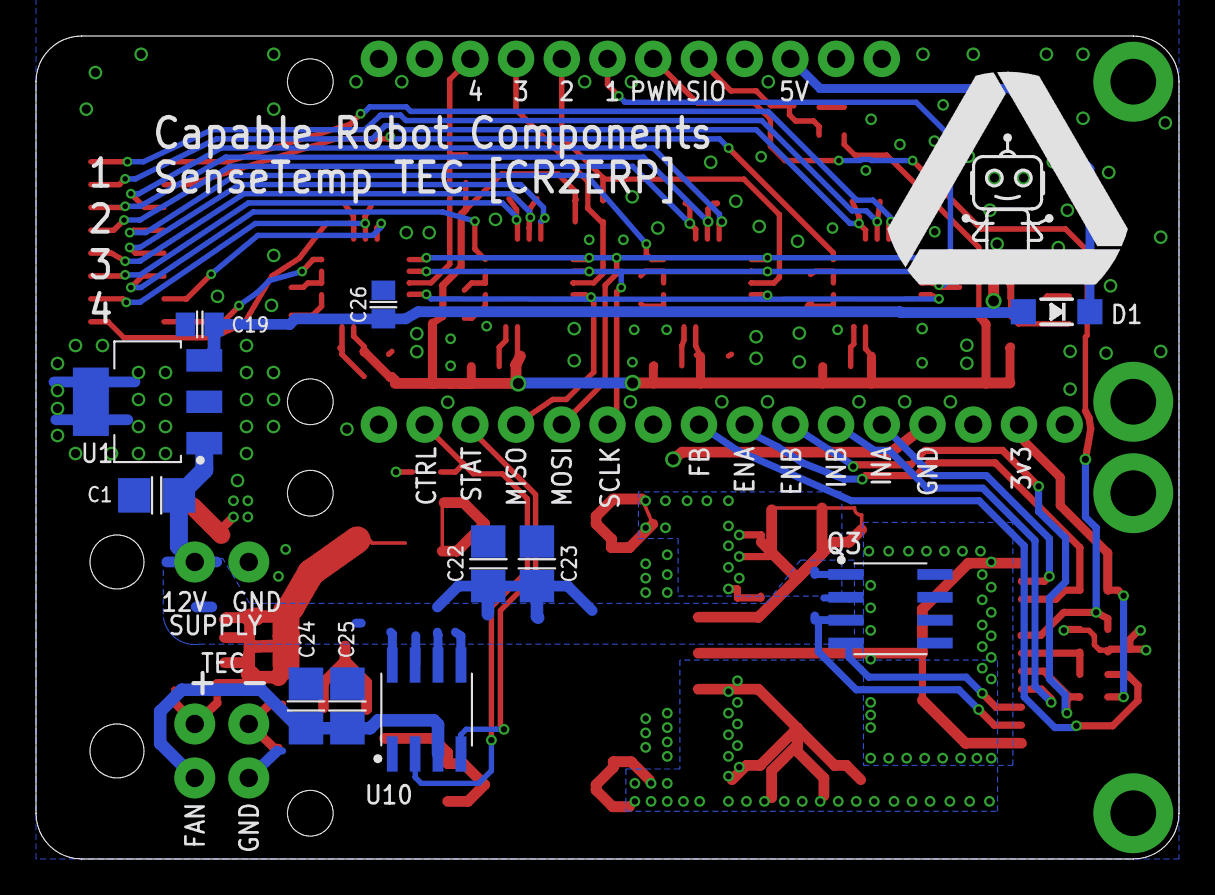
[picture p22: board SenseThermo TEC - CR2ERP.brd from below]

Board: 2 copper layers, 63.5 x 45.7 mm, 67 parts (12 on the bottom side), 61 nets.

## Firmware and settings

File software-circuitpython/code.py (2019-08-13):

## CircuitPython Imports
import digitalio
import analogio
import pulseio
import busio
import supervisor
import board
import time
import neopixel

## Local Imports
import adafruit_max31865 as max31865
import vnh5019

def mean(data):
    return sum(data)/float(len(data))

def _ss(data):
    c = mean(data)
    ss = sum((x-c)**2 for x in data)
    return ss

def stddev(data, ddof=0):
    ss = _ss(data)
    pvar = ss/(len(data)-ddof)
    return pvar**0.5

RTD_NOMINAL   = 1000.0  ## Resistance of RTD at 0C
RTD_REFERENCE = 4300.0  ## Value of reference resistor on PCB

spi = busio.SPI(board.SCK, MOSI=board.MOSI, MISO=board.MISO)

## Create SPI Chip Select pins
cs1  = digitalio.DigitalInOut(board.D10)
cs2  = digitalio.DigitalInOut(board.D9)
cs3  = digitalio.DigitalInOut(board.D6)
cs4  = digitalio.DigitalInOut(board.D5)
css  = [cs1, cs2, cs3, cs4]

sensors = []
pixel = False

if hasattr(board, 'NEOPIXEL'):
    led = neopixel.NeoPixel(board.NEOPIXEL, 1)
    led.brightness = 0.3
    pixel = True

## Create array for the RTD sensors on the SenseTemp Wing
for cs in css:
    cs.switch_to_output(digitalio.DriveMode.PUSH_PULL)

    sensors.append(
        max31865.MAX31865(
            spi, cs,
            wires        = 4,
            rtd_nominal  = RTD_NOMINAL,
            ref_resistor = RTD_REFERENCE
        )
    )

redled = digitalio.DigitalInOut(board.D13)
redled.switch_to_output(digitalio.DriveMode.PUSH_PULL)

ON = 0.05

def wheel(pos):
    # Input a value 0 to 255 to get a color value.
    # The colours are a transition r - g - b - back to r.
    if pos < 0:
        return 0, 0, 0

    if pos > 255:
        return 255, 0, 0

    if pos < 85:
        return int(255 - pos * 3), int(pos * 3), 0

    if pos < 170:
        pos -= 85
        return 0, int(255 - pos * 3), int(pos * 3)

    pos -= 170
    return int(pos * 3), 0, int(255 - (pos * 3))




pins = dict(
    ina=board.A0, inb=board.A1,
    diaga=board.A3, diagb=board.A2, 
    pwm=board.D11, fb=board.A4
)

vnh = vnh5019.VNH5019(pins)
aux = pulseio.PWMOut(board.TX, frequency=100) 

def fan(value):
    aux.duty_cycle = value

def tec(value):
    vnh.set(value)

def temps():
    data = [sensor.temperature for sensor in sensors]
    print(data)

while True:
    # print("faults  : {} {}".format(*vnh.faults()))
    # print("current : {}".format(vnh.current()))

    led.value = True
    time.sleep(ON)
    led.value = False
    time.sleep(1.0 - ON)

    data = [sensor.temperature for sensor in sensors]

    if pixel:
        # Scale and reverse colors so that high temperatures (30C) -> red color
        color = 255 - data[0]*7
        led.fill(wheel(int(color)))

    if supervisor.runtime.serial_connected:
        print(data, mean(data), max(data) - min(data), stddev(data))
        time.sleep(0.3)

    time.sleep(0.2)

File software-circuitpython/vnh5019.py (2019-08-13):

import digitalio
import analogio
import pulseio

class VNH5019:

    def __init__(self, pins):
        self.pins = pins
        self.state = 0

        self.setup_pins()

    def setup_pins(self):
        self.ina = digitalio.DigitalInOut(self.pins['ina'])
        self.ina.switch_to_output(digitalio.DriveMode.PUSH_PULL)

        self.inb = digitalio.DigitalInOut(self.pins['inb'])
        self.inb.switch_to_output(digitalio.DriveMode.PUSH_PULL)

        self.diaga = digitalio.DigitalInOut(self.pins['diaga'])
        self.diaga.switch_to_input(pull=digitalio.Pull.UP)

        self.diagb = digitalio.DigitalInOut(self.pins['diagb'])
        self.diagb.switch_to_input(pull=digitalio.Pull.UP)

        self.fb = analogio.AnalogIn(self.pins['fb'])

        self.pwm = pulseio.PWMOut(self.pins['pwm'], frequency=20000) 

    def set(self, rate):

        # Ignore values that are out of bounds
        if abs(rate) >= 2**16:
            return

        if rate > 0:
            if self.state <= 0:
                print("State {} to 1".format(self.state))
                self.inb.value = False
                self.ina.value = True
                self.state = 1

        elif rate < 0:
            if self.state >= 0:
                print("State {} to -1".format(self.state))
                self.ina.value = False
                self.inb.value = True
                self.state = -1
        else:
            self.state = 0
            self.ina.value = False
            self.inb.value = False


        self.pwm.duty_cycle = abs(rate)

    def faults(self):
        return (not self.diaga.value, not self.diagb.value)

    def current(self):
        voltage = float(self.fb.value) * self.fb.reference_voltage / 2**16
        current = voltage / 0.14
        return current

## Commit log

2018-12-18 Adding CRHVEF prototype version.
    [SenseThermo TEC - CRHVEF.brd, SenseThermo TEC - CRHVEF.sch]
2018-12-19 Initial commit of CR2ERP version. Fixed footprint of MAX31865 RTD ICs
    [SenseThermo TEC - CR2ERP.brd, SenseThermo TEC - CR2ERP.sch]
2018-12-19 Remove 5v to 3v regulator (will be replaced by 12v to 3v regulator. Change TEC PWM pin.
    [SenseThermo TEC - CR2ERP.brd, SenseThermo TEC - CR2ERP.sch]
2018-12-19 Added 12v to 5v regulator and 5v to 3v regulators. Changed RTD passives to 0603
    [SenseThermo TEC - CR2ERP.brd, SenseThermo TEC - CR2ERP.sch]
2018-12-19 Added high side switch for fan. Silkscreen changes.
    [SenseThermo TEC - CR2ERP.brd, SenseThermo TEC - CR2ERP.sch]
2018-12-19 Move R8 away from U5
    [SenseThermo TEC - CR2ERP.brd]
2019-08-13 Update to released version of CR2ERP
    [Bill of Materials.csv, SenseTemp TEC BOM.xlsx, SenseThermo TEC - CR2ERP.brd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]
2019-08-13 Added CircuitPython VNH5019 library and example usage code
2019-10-25 Remove extraneous files
    [SenseTemp TEC BOM.xlsx, bom_macrofab.xlsx]

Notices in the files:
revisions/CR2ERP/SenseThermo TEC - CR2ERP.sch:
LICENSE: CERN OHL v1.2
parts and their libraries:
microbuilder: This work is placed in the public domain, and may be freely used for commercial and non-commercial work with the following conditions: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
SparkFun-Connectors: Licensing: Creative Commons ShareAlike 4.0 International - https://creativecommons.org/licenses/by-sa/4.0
